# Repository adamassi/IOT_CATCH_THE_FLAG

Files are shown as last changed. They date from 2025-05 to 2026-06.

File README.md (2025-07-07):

## CAPTURE THE FLAG Project by :  Firas Hilu, Adam Assi, Jimmy Bittar
  Type It, Robot Builds It!
  The project is a robot that receives a word from the user, detects relevant letter cubes, and places them in the correct order in a designated area.
## Details about the project
   Main Features:
  - Real-time 3D object tracking via OptiTrack
  - Autonomous path planning using RRT* for obstacle avoidance
  - Full spelling pipeline: input, detection, pickup, transport, and placement
  This project demonstrates a flexible robotic framework for real-time
  object handling using motion capture and path planning.

## Hardware used:
  - ESP32 CH9102
  - Car platform PCB
  - L293D driver
  - 4 DC motors
  - Active Buzzer
  - Micro servo
  - 9V / 12V battery
  - LM2596 DC-DC Buck Converter Module
  - Optitrack markers
  * note: in the platform we used, the ENA and ENB of the driver were connected together, so in order to be able to control the speed of each side separately, we didnt use libraries for controlling the speed, but we wrote the code of the ESP for controlling the motors using PWM on th IN1, IN2, IN3, IN4.
    
## Folder description :
* ESP32: source code for the esp
* path_algorithms: files used in planning the algorithm
* Documentation: wiring diagram + poster + 3d printed parts
* Unit Tests: tests for individual hardware components
* PARAMETERS.py: contains the parameters and settings that can be modified in the code - hardcoded parameters.

## ESP32 SDK version used in this project: 
"esp32" SDK version 2.0.17 by Espressif Systems.

## Arduino/ESP32 libraries used in this project:
* WiFi - version 2.0.17 (from esp32 core by Espressif Systems)
* AsyncTCP - version 3.3.2
* ESPAsyncWebServer - version 3.6.0
* ESP32Servo - version 3.0.6

## Connection diagram:
diagram

## Project Poster:
Capture_The_Falg_poster

This project is part of ICST - The Interdisciplinary Center for Smart Technologies, Taub Faculty of Computer Science, Technion
https://icst.cs.technion.ac.il/

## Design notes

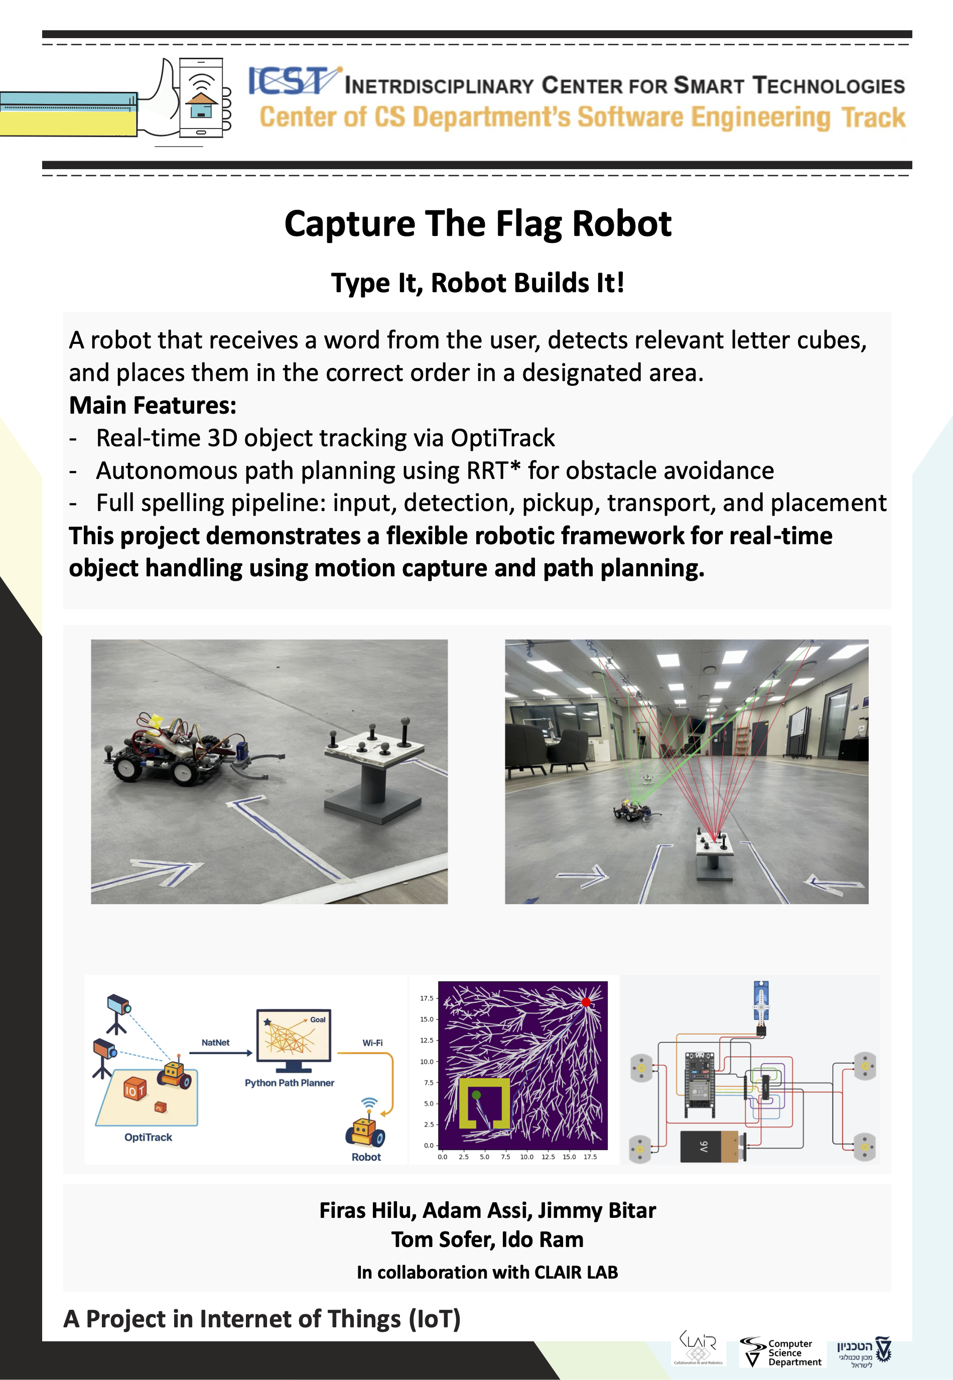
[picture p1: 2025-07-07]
assests/Capture_The_Falg_poster.png

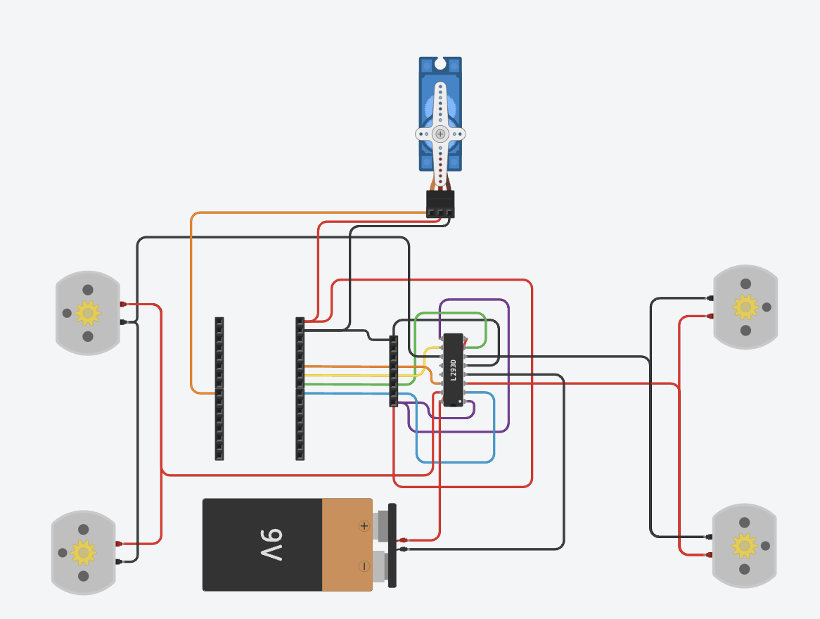
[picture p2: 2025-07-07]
assests/diagram.png

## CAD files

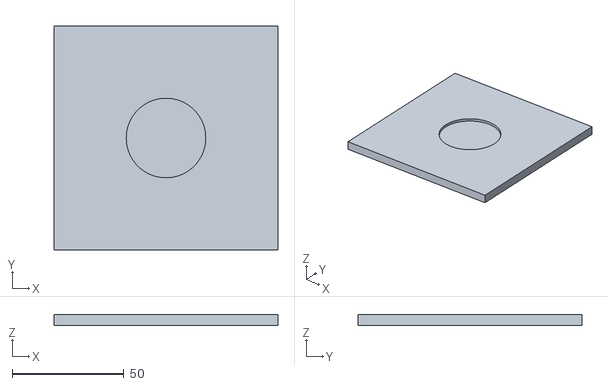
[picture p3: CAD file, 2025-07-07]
assests/3d_printing/top_part.stl
100.0 x 100.0 x 5.00

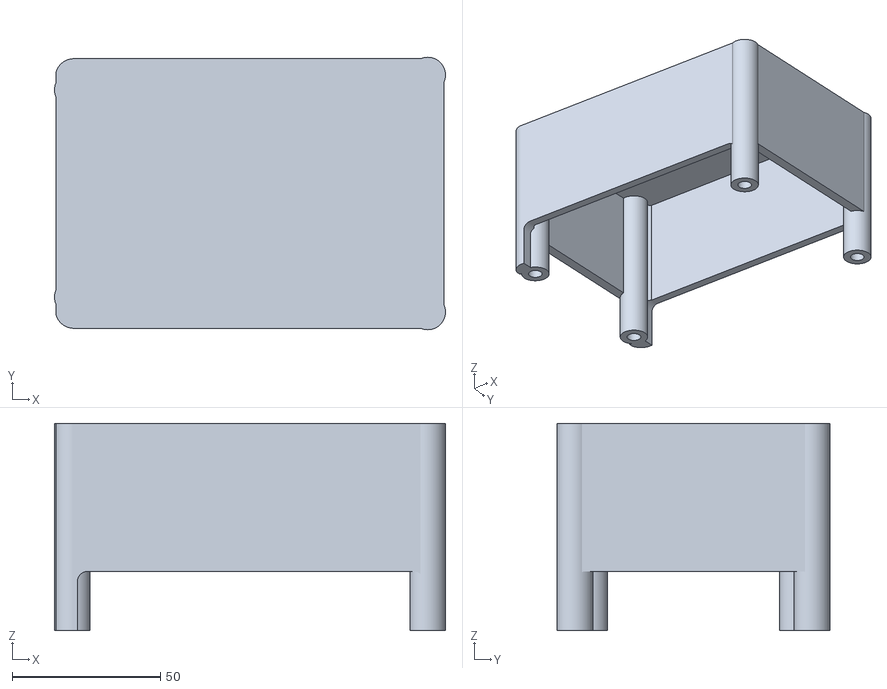
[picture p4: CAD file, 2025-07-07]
assests/3d_printing/IOT_robot_case.stl
132.0 x 92.0 x 70.0

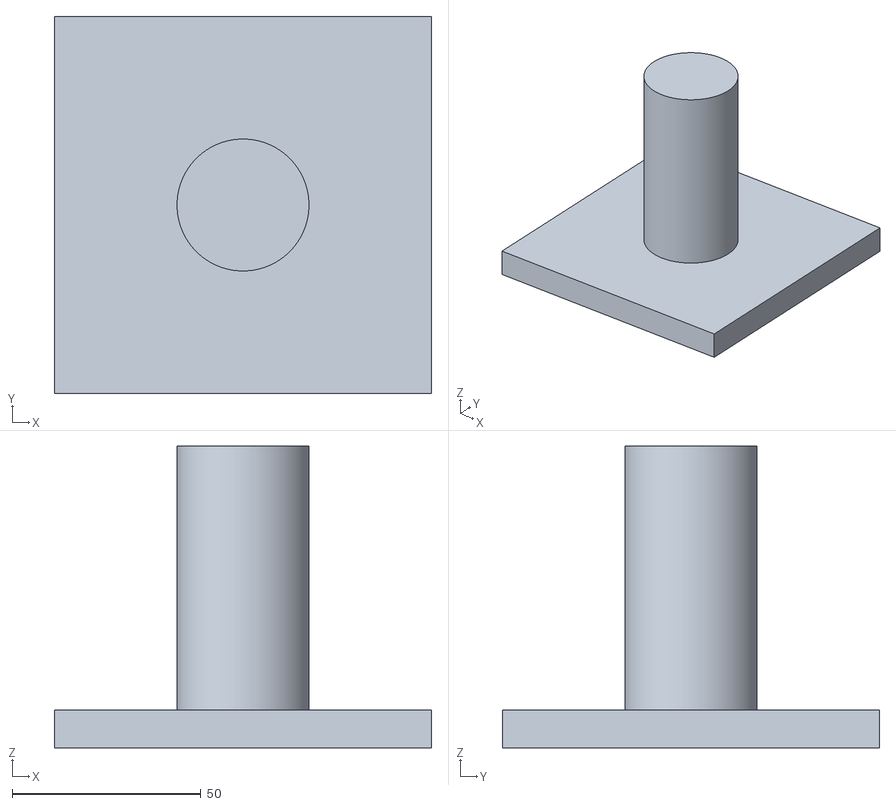
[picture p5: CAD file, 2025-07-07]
assests/3d_printing/base_part.stl
100.0 x 100.0 x 80.0

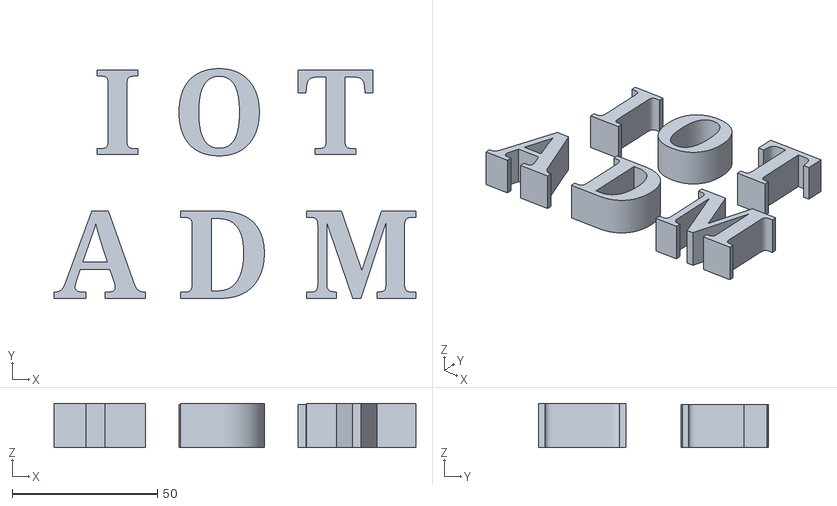
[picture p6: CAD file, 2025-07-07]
assests/3d_printing/letters.stl
124.5 x 79.0 x 15.1

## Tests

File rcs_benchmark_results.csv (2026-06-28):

run_index | start_x | start_y | goal_x | goal_y | success | path_length | time_seconds
1 | -0.2099 | -0.9652 | 1.0777 | -0.6967 | 1 | 1.8018 | 4.375302
2 | 0.3596 | -0.9543 | -1.3736 | 0.0534 | 1 | 2.4399 | 14.167814
3 | -1.69 | -0.6077 | 1.5716 | -1.6594 | 1 | 4.2871 | 45.078915
4 | 2.8974 | 0.3119 | 2.6241 | -0.6205 | 1 | 1.1972 | 1.89203
5 | -0.5476 | 1.877 | 3.1428 | -1.5742 | 1 | 5.5842 | 58.885434
6 | 2.1586 | 0.9652 | 3.498 | -1.1967 | 1 | 3.18 | 24.669612
7 | -2.0207 | 1.7797 | -3.8503 | -0.3494 | 1 | 3.1694 | 22.683516
8 | -3.6902 | -0.1207 | 0.8395 | -0.6447 | 1 | 6.4344 | 38.249741
9 | 0.0886 | -0.6658 | -2.5479 | -0.3662 | 1 | 4.2241 | 38.933603
10 | -0.2804 | 1.0991 | 1.4629 | -1.0494 | 1 | 2.9599 | 27.331372
11 | -1.9977 | -1.2285 | 3.2131 | -0.4567 | 1 | 7.0341 | 65.185963
12 | 0.279 | -0.5471 | -2.6854 | -0.0939 | 1 | 4.1928 | 24.214959
13 | -2.4742 | 0.8403 | 1.1673 | 0.029 | 1 | 4.7138 | 26.431936
14 | 0.036 | -1.6032 | 0.8234 | 0.67 | 1 | 3.2667 | 5.709921
15 | -3.3224 | -1.4972 | -0.6924 | 0.8983 | 1 | 3.9911 | 6.893601
16 | -3.33 | 0.2276 | -2.1221 | 1.3979 | 1 | 1.8093 | 0.941159
17 | 2.8716 | -0.8355 | 3.4137 | -0.3585 | 1 | 0.7308 | 0.493155
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

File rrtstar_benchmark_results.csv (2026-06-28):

run_index | start_x | start_y | goal_x | goal_y | success | path_length | time_seconds
1 | 2.8825 | -1.5846 | 0.3958 | -1.8374 | 1 | 2.5739 | 0.457899
2 | 2.4377 | 0.7294 | -2.9072 | -1.2642 | 1 | 5.913 | 0.504726
3 | -3.7297 | -0.6265 | -3.007 | 0.1249 | 1 | 1.2856 | 0.219742
4 | -0.7057 | -0.5253 | -0.6808 | 0.3606 | 1 | 0.9703 | 0.186255
5 | -0.6485 | -1.8988 | 0.8873 | -1.7884 | 1 | 1.6308 | 0.198096
6 | 0.0811 | -1.3204 | 2.2872 | -1.0073 | 1 | 2.3257 | 0.280202
7 | 1.957 | -1.6852 | -0.2862 | -1.6783 | 1 | 2.5583 | 0.299143
8 | -3.2804 | 1.6072 | -2.7467 | -0.3219 | 1 | 2.4723 | 0.321626
9 | -2.6899 | 0.793 | 3.1886 | 1.4603 | 1 | 6.3777 | 0.76219
10 | 0.7464 | -0.3033 | -2.0113 | -0.315 | 1 | 2.9263 | 0.278232
11 | 0.7957 | 1.8009 | -2.0193 | -0.1743 | 1 | 3.6606 | 0.349373
12 | -1.2972 | 1.2988 | -3.6014 | -0.1318 | 1 | 2.7683 | 0.281091
13 | -3.0521 | 1.72 | 1.8487 | 1.638 | 1 | 5.0096 | 0.3935
14 | 0.0059 | -1.6769 | -0.4604 | 0.3023 | 1 | 2.1244 | 0.232812
15 | -0.361 | 1.0712 | 1.503 | 0.5845 | 1 | 2.0824 | 0.275678
16 | -3.6821 | 0.1028 | 3.3516 | -1.6248 | 1 | 7.5785 | 0.660558
17 | 0.1883 | 1.8255 | 1.5458 | -1.3127 | 1 | 3.4499 | 0.43348
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

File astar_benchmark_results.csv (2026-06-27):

run_index | start_x | start_y | goal_x | goal_y | success | path_length | time_seconds
1 | 3.6898 | 0.2818 | 1.3687 | -0.8646 | 1 | 2.5888 | 0.567852
2 | 0.469 | -1.6728 | 1.8175 | -1.5676 | 1 | 1.3526 | 0.446736
3 | 3.3861 | 0.8448 | 3.6451 | 0.0311 | 1 | 0.8539 | 0.512764
4 | 0.1999 | -1.7176 | -0.1534 | 0.0411 | 1 | 1.7938 | 0.467693
5 | 1.7088 | 1.1359 | -0.5832 | -0.4615 | 1 | 2.7938 | 0.718417
6 | 1.9346 | -0.1076 | 2.7815 | -1.0605 | 1 | 1.2749 | 0.466033
7 | 0.329 | -1.2217 | -2.6064 | -1.4685 | 1 | 2.9458 | 0.424948
8 | -0.262 | 1.2786 | 1.3341 | 1.1252 | 1 | 1.6034 | 0.453101
9 | -1.4095 | -0.8809 | 2.7189 | 1.1898 | 1 | 4.6185 | 0.564341
10 | 0.1079 | -0.4643 | 0.1198 | 0.8552 | 1 | 1.3196 | 0.4681
11 | 2.794 | 0.4617 | 1.2769 | -0.6978 | 1 | 1.9094 | 0.512458
12 | -3.0079 | 1.3215 | -2.1455 | -0.5634 | 1 | 2.0728 | 0.491075
13 | -1.4265 | -1.2238 | -0.615 | -0.7387 | 1 | 0.9455 | 0.600992
14 | -0.4027 | -0.1542 | -0.8228 | 0.1311 | 1 | 0.5079 | 0.477805
15 | -2.8718 | -0.2451 | -3.5092 | -0.6103 | 1 | 0.7346 | 0.464533
16 | 1.8232 | -0.5731 | -0.3897 | 0.8329 | 1 | 2.6217 | 0.441428
17 | 0.5724 | -0.9694 | 2.3217 | 1.7248 | 1 | 3.4668 | 0.462753
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

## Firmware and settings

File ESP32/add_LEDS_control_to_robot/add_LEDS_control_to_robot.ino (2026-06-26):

#include <WiFi.h>
#include <AsyncTCP.h>
#include <ESPAsyncWebServer.h>
#include <ESP32Servo.h>
#include <Adafruit_NeoPixel.h>


#ifdef __AVR__
 #include <avr/power.h> // Required for 16 MHz Adafruit Trinket
#endif










// Which pin on the Arduino is connected to the NeoPixels?
#define LEDPIN  19
// How many NeoPixels are attached to the Arduino?
#define NUMPIXELS 6 // Popular NeoPixel ring size

Adafruit_NeoPixel pixels(NUMPIXELS, LEDPIN, NEO_GRB + NEO_KHZ800);


Servo myServo;


// WiFi credentials  router name and password
const char *ssid = "IOT_project";     //remember to change
const char *password = "Arduino123";  //remember to change

int ENA_pin = 13;

int IN1 = 27;
int IN2 = 26;
int IN3 = 25;
int IN4 = 33;

const int servoPin = 15;
//beeper
const int beeperPin = 23;
TaskHandle_t beepingTaskHandle = NULL;
volatile bool keepBeeping = false;

String slider_value = "0";
int pwm_power_value = 45;

int servoAngle = 10;

const int frequency = 500;
// l1() l4 responsible go backward
// l2 (right) and l3(left) responsible go forward 
const int pwm_channel1 = 5;
const int pwm_channel2 = 2;
const int pwm_channel3 = 3;
const int pwm_channel4 = 4;
// const int servo_channel = 1;
const int resolution = 8;

const char *input_parameter = "value";

AsyncWebServer server(80);

const char index_html[] PROGMEM = R"rawliteral(
<!DOCTYPE HTML><html>
<head>
  <meta name="viewport" content="width=device-width, initial-scale=1">
  <title>DC Motor Speed Control Web Server</title>
  <style>
    html {font-family: Times New Roman; display: inline-block; text-align: center;}
    h2 {font-size: 2.3rem;}
    p {font-size: 2.0rem;}
    body {max-width: 400px; margin:0px auto; padding-bottom: 25px;}
    .slider { -webkit-appearance: none; margin: 14px; width: 360px; height: 25px; background: #4000ff;
      outline: none; -webkit-transition: .2s; transition: opacity .2s;}
    .slider::-webkit-slider-thumb {-webkit-appearance: none; appearance: none; width: 35px; height: 35px; background:#01070a; cursor: pointer;}
    .slider::-moz-range-thumb { width: 35px; height: 35px; background: #01070a; cursor: pointer; } 
    .btn {padding: 16px 24px; margin: 10px; font-size: 18px; background-color: #008CBA; color: white; border: none; cursor: pointer; border-radius: 8px;}
    .btn:hover {background-color: #005f73;}
  </style>
</head>
<body>
  <p><strong>Servo Angle</strong></p>
  <span id="servo_angle_display">%SERVOANGLE%</span>°
  <input type="range" onchange="updateServoAngle(this)" id="servoSlider" min="0" max="90" value="%SERVOANGLE%" step="1" class="slider">


  <h2>DC Motor Speed Control Web Server</h2>
  <p><span id="textslider_value">%SLIDERVALUE%</span></p>
  <p><input type="range" onchange="updateSliderPWM(this)" id="pwmSlider" min="-255" max="255" value="%SLIDERVALUE%" step="1" class="slider"></p>
  
  <p><strong>PWM Power</strong></p>
  <p><span id="pwm_power_display">%SLIDERPWMVALUE%</span></p>
  <input type="range" onchange="updatePWMSlider(this)" id="pwmPowerSlider" min="0" max="255" value="%SLIDERPWMVALUE%" step="1" class="slider">
  

  <p>
    <button class="btn" onclick="goForward()">Forward</button><br>
    <button class="btn" onclick="turnLeft()">Left</button>
    <button class="btn" onclick="stopMotor()">Stop</button>
    <button class="btn" onclick="turnRight()">Right</button><br>
    <button class="btn" onclick="goBackward()">Backward</button>
  </p>

<script>

function updateServoAngle(element) {
  var angle = document.getElementById("servoSlider").value;
  document.getElementById("servo_angle_display").innerHTML = angle;
  var xhr = new XMLHttpRequest();
  xhr.open("GET", "/servo?value=" + angle, true);
  xhr.send();
}

function updateSliderPWM(element) {
  var slider_value = document.getElementById("pwmSlider").value;
  document.getElementById("textslider_value").innerHTML = slider_value;
  var xhr = new XMLHttpRequest();
  xhr.open("GET", "/slider?value=" + slider_value, true);
  xhr.send();
}

function updatePWMSlider(element) {
  var pwm_value = document.getElementById("pwmPowerSlider").value;
  document.getElementById("pwm_power_display").innerHTML = pwm_value;
  var xhr = new XMLHttpRequest();
  xhr.open("GET", "/set_pwm_power?value=" + pwm_value, true);
  xhr.send();
}

function stopMotor() {
  var xhr = new XMLHttpRequest();
  xhr.open("GET", "/stop", true);
  xhr.send();
  document.getElementById("pwmSlider").value = 0;
  document.getElementById("textslider_value").innerHTML = 0;
}

function goForward() {
  var xhr = new XMLHttpRequest();
  xhr.open("GET", "/go", true);
  xhr.send();
}

function goBackward() {
  var xhr = new XMLHttpRequest();
  xhr.open("GET", "/back", true);
  xhr.send();
}

function turnLeft() {
  var xhr = new XMLHttpRequest();
  xhr.open("GET", "/left", true);
  xhr.send();
}

function turnRight() {
  var xhr = new XMLHttpRequest();
  xhr.open("GET", "/right", true);
  xhr.send();
}

window.addEventListener("keydown", function(e) {
  if(["ArrowUp", "ArrowDown", "ArrowLeft", "ArrowRight", " "].includes(e.key)) {
    e.preventDefault();
  }
}, false);

document.addEventListener("keydown", function(event) {
 switch(event.key) {
    case "ArrowUp":
      goForward();
      break;
    case "ArrowDown":
      goBackward();
      break;
    case "ArrowLeft":
      turnLeft();
      break;
    case "ArrowRight":
      turnRight();
      break;
    case " ":
      stopMotor();
      break;
  }
});
</script>
</body>
</html>
)rawliteral";


// String processor(const String &var) {
//   if (var == "SLIDERVALUE") {
//     return slider_value;
//   }
//   return String();
// }

// String processor(const String &var) {
//   if (var == "SLIDERVALUE") {
//     return slider_value;
//   } else if (var == "SLIDERPWMVALUE") {
//     return String(pwm_power_value);
//   }
//   return String();
// }

String processor(const String &var) {
  if (var == "SLIDERVALUE") {
    return slider_value;
  } else if (var == "SLIDERPWMVALUE") {
    return String(pwm_power_value);
  } else if (var == "SERVOANGLE") {
    return String(servoAngle);
  }
  return String();
}


//beeper
void repeatedBeepTask(void *param) {
  int *durations = (int *)param;
  int onDuration = durations[0];
  int offDuration = durations[1];
  delete[] durations;

  while (keepBeeping) {
    digitalWrite(beeperPin, HIGH);
    vTaskDelay(onDuration / portTICK_PERIOD_MS);
    digitalWrite(beeperPin, LOW);
    vTaskDelay(offDuration / portTICK_PERIOD_MS);
  }

  digitalWrite(beeperPin, LOW);  // Ensure off
  beepingTaskHandle = NULL;
  vTaskDelete(NULL);
}



void setup() {
  Serial.begin(115200);
  delay(1000);
  pinMode(ENA_pin, OUTPUT);
  pinMode(IN1, OUTPUT);
  pinMode(IN2, OUTPUT);
  pinMode(IN3, OUTPUT);
  pinMode(IN4, OUTPUT);
  pinMode(LEDPIN, OUTPUT);

  ledcSetup(pwm_channel1, frequency, resolution);
  ledcSetup(pwm_channel2, frequency, resolution);
  ledcSetup(pwm_channel3, frequency, resolution);
  ledcSetup(pwm_channel4, frequency, resolution);

  ledcAttachPin(IN1, pwm_channel1);
  ledcAttachPin(IN2, pwm_channel2);
  ledcAttachPin(IN3, pwm_channel3);
  ledcAttachPin(IN4, pwm_channel4);

  digitalWrite(ENA_pin, LOW);
  ledcWrite(pwm_channel1, 0);
  ledcWrite(pwm_channel2, 0);
  ledcWrite(pwm_channel3, 0);
  ledcWrite(pwm_channel4, 0);
  digitalWrite(ENA_pin, HIGH);


  pixels.begin();
  pixels.clear(); // Initialize all pixels to 'off'


  for(int i=0; i<NUMPIXELS; i++){
      pixels.setPixelColor(i, pixels.Color(255, 0, 0)); // Red color
  }
  pixels.show(); // Update the strip to display the new colors


  // ledcSetup(servo_channel, frequency, resolution);
  // ledcAttachPin(servoPin, servo_channel);
  myServo.attach(servoPin);

  pinMode(beeperPin, OUTPUT);
  digitalWrite(beeperPin, LOW);  // Ensure it's off initially


  WiFi.begin(ssid, password);
  while (WiFi.status() != WL_CONNECTED) {
    // delay(1000);
    // Serial.println("Connecting...");
    pixels.clear(); // Clear previous colors
    delay(500);
    
    for(int i=0; i<NUMPIXELS; i++){
      pixels.setPixelColor(i, pixels.Color(0, 0, 255)); // blue color
    }
  Serial.println("Connecting...");
  pixels.show(); // Update the strip to display the new colors
  delay(500);
  }
  for(int i=0; i<NUMPIXELS; i++){
    pixels.setPixelColor(i, pixels.Color(0, 255, 0)); // green color
  }
  pixels.show(); // Update the strip to display the new colors

  Serial.println(WiFi.localIP());

  server.on("/", HTTP_GET, [](AsyncWebServerRequest *request) {
    request->send_P(200, "text/html", index_html, processor);
  });



  server.on("/slider", HTTP_GET, [](AsyncWebServerRequest *request) {
    String message;
    if (request->hasParam(input_parameter)) {
      message = request->getParam(input_parameter)->value();
      slider_value = message;

      int val = slider_value.toInt();
      int pwm_value = abs(val);  // Always a positive PWM

      // Determine motor direction
      if (val > 0) {
        // Forward
        ledcWrite(pwm_channel1, 0);    // IN1 LOW
        ledcWrite(pwm_channel2, val);  // IN2 PWM -> Forward speed
        ledcWrite(pwm_channel3, val);  // IN3 PWM -> Forward speed
        ledcWrite(pwm_channel4, 0);    // IN4 LOW

      } else if (val < 0) {
        // Reverse
        val = -val;                    // Make val positive for PWM
        ledcWrite(pwm_channel1, val);  // IN1 PWM -> Reverse speed
        ledcWrite(pwm_channel2, 0);    // IN2 LOW
        ledcWrite(pwm_channel3, 0);    // IN3 LOW
        ledcWrite(pwm_channel4, val);  // IN4 PWM -> Reverse speed

      } else {
        // Stop
        ledcWrite(pwm_channel1, 0);
        ledcWrite(pwm_channel2, 0);
        ledcWrite(pwm_channel3, 0);
        ledcWrite(pwm_channel4, 0);
      }

      // Apply PWM regardless of direction
    } else {
      message = "No message sent";
    }
    Serial.println(message);
    request->send(200, "text/plain", "OK");
  });

  server.on("/set_pwm_power", HTTP_GET, [](AsyncWebServerRequest *request) {
    if (request->hasParam(input_parameter)) {
      pwm_power_value = request->getParam(input_parameter)->value().toInt();
      Serial.print("PWM power updated: ");
      Serial.println(pwm_power_value);
    }
    request->send(200, "text/plain", "PWM power updated");
  });

  server.on("/stop", HTTP_GET, [](AsyncWebServerRequest *request) {
    //slider_value = "0";
    ledcWrite(pwm_channel1, 0);
    ledcWrite(pwm_channel2, 0);
    ledcWrite(pwm_channel3, 0);
    ledcWrite(pwm_channel4, 0);

    request->send(200, "text/plain", "Motor stopped");
  });

  server.on("/go", HTTP_GET, [](AsyncWebServerRequest *request) {
    //slider_value = "150";
    ledcWrite(pwm_channel1, 0);
    ledcWrite(pwm_channel2, 250);
    ledcWrite(pwm_channel3, 250);
    ledcWrite(pwm_channel4, 0);

    request->send(200, "text/plain", "Motor go");
  });

  server.on("/back", HTTP_GET, [](AsyncWebServerRequest *request) {
    //slider_value = "150";
    ledcWrite(pwm_channel1, 250);
    ledcWrite(pwm_channel2, 0);
    ledcWrite(pwm_channel3, 0);
    ledcWrite(pwm_channel4, 250);

    request->send(200, "text/plain", "Back");
  });

  server.on("/right", HTTP_GET, [](AsyncWebServerRequest *request) {
    //slider_value = "150";
    int speed = pwm_power_value;
    if (request->hasParam(input_parameter)) {
      speed = request->getParam(input_parameter)->value().toInt();
    }
    ledcWrite(pwm_channel1, speed);
    ledcWrite(pwm_channel2, 0);
    ledcWrite(pwm_channel3, speed);
    ledcWrite(pwm_channel4, 0);

    request->send(200, "text/plain", "turn right");
  });
  server.on("/right_moving", HTTP_GET, [](AsyncWebServerRequest *request) {
    //slider_value = "150";
    int speed = pwm_power_value;
    if (request->hasParam(input_parameter)) {
      speed = request->getParam(input_parameter)->value().toInt();
    }
    ledcWrite(pwm_channel1, speed);
    ledcWrite(pwm_channel2, 0);
    ledcWrite(pwm_channel3, speed);
    ledcWrite(pwm_channel4, 0);

    request->send(200, "text/plain", "turn right");
  });

  server.on("/left", HTTP_GET, [](AsyncWebServerRequest *request) {
    //slider_value = "150";
    int speed = pwm_power_value;
    if (request->hasParam(input_parameter)) {
      speed = request->getParam(input_parameter)->value().toInt();
    }
    ledcWrite(pwm_channel1, 0);
    ledcWrite(pwm_channel2, speed);
    ledcWrite(pwm_channel3, 0);
    ledcWrite(pwm_channel4, speed);

    request->send(200, "text/plain", "turn left");
  });

  server.on("/steer", HTTP_GET, [](AsyncWebServerRequest *request) {
    int left_speed = 0;
    int right_speed = 0;

    // Check if both parameters exist
    if (request->hasParam("left") && request->hasParam("right")) {
      left_speed = request->getParam("left")->value().toInt();
      right_speed = request->getParam("right")->value().toInt();
    } else {
      request->send(400, "text/plain", "Missing 'left' or 'right' parameter");
      return;
    }

    // Set motor speeds
    ledcWrite(pwm_channel1, 0);
    ledcWrite(pwm_channel2, right_speed);
    ledcWrite(pwm_channel3, left_speed);
    ledcWrite(pwm_channel4, 0);

    // Respond to client
    request->send(200, "text/plain", "Steering updated");
  });

  server.on("/servo", HTTP_GET, [](AsyncWebServerRequest *request) {
    if (request->hasParam(input_parameter)) {
      int angle = request->getParam(input_parameter)->value().toInt();
      angle = constrain(angle, 0, 90);  // Ensure within valid range
      myServo.write(angle);
      servoAngle = angle;
      Serial.printf("Servo angle set to: %d\n", angle);
      request->send(200, "text/plain", "Servo angle set to " + String(angle));
    } else {
      request->send(400, "text/plain", "Missing angle parameter");
    }
  });

  server.on("/beep", HTTP_GET, [](AsyncWebServerRequest *request) {
    if (request->hasParam("duration")) {
      int duration = request->getParam("duration")->value().toInt();
      duration = constrain(duration, 1, 5000);  // Max 5 seconds safety limit

      digitalWrite(beeperPin, HIGH);  // Turn beeper on
      Serial.printf("Beeping for %d ms\n", duration);

      // Use a timer (non-blocking) via a task or schedule
      // For now, use delay in a simple task
      xTaskCreatePinnedToCore(
        [](void *param) {
          int d = *((int *)param);
          vTaskDelay(d / portTICK_PERIOD_MS);
          digitalWrite(beeperPin, LOW);  // Turn it off
          delete (int *)param;
          vTaskDelete(NULL);
        },
        "BeeperTask", 2048, new int(duration), 1, NULL, 1);

      request->send(200, "text/plain", "Beeping for " + String(duration) + " ms");
    } else {
      request->send(400, "text/plain", "Missing 'duration' parameter");
    }
  });

  server.on("/start_beeping", HTTP_GET, [](AsyncWebServerRequest *request) {
    if (beepingTaskHandle != NULL) {
      request->send(400, "text/plain", "Beeping already running");
      return;
    }

    if (request->hasParam("on") && request->hasParam("off")) {
      int onTime = request->getParam("on")->value().toInt();
      int offTime = request->getParam("off")->value().toInt();

      onTime = constrain(onTime, 10, 5000);
      offTime = constrain(offTime, 10, 5000);

      keepBeeping = true;

      int *durations = new int[2]{ onTime, offTime };

      xTaskCreatePinnedToCore(
        repeatedBeepTask, "RepeatedBeepTask", 2048, durations, 1, &beepingTaskHandle, 1);

      request->send(200, "text/plain", "Started beeping");
    } else {
      request->send(400, "text/plain", "Missing 'on' or 'off' parameter");
    }
  });

  server.on("/stop_beeping", HTTP_GET, [](AsyncWebServerRequest *request) {
    keepBeeping = false;
    request->send(200, "text/plain", "Stopped beeping");
  });
  server.on("/connecting",HTTP_GET, [](AsyncWebServerRequest *request) {
    
    pixels.clear(); // Set all pixel colors to 'off'

    for (int i = 0; i < NUMPIXELS; i++) {
        pixels.setPixelColor(i, pixels.Color(0, 0, 255)); // Blue
      }
    
      pixels.show();
    request->send(200, "text/plain", "LED blue");
  });
  server.on("/lights_peach", HTTP_GET, [](AsyncWebServerRequest *request) {
  pixels.clear();

  for (int i = 0; i < NUMPIXELS; i++) {
    pixels.setPixelColor(i, pixels.Color(0, 50, 250)); // Peach
  }

  pixels.show();
  request->send(200, "text/plain", "Lights set to peach");
});


server.on("/lights_color", HTTP_GET, [](AsyncWebServerRequest *request) {
  if (
    request->hasParam("red") &&
    request->hasParam("green") &&
    request->hasParam("blue")
  ) {
    int red = request->getParam("red")->value().toInt();
    int green = request->getParam("green")->value().toInt();
    int blue = request->getParam("blue")->value().toInt();

    red = constrain(red, 0, 255);
    green = constrain(green, 0, 255);
    blue = constrain(blue, 0, 255);

    pixels.clear();

    for (int i = 0; i < NUMPIXELS; i++) {
      pixels.setPixelColor(i, pixels.Color(red, green, blue));
    }

    pixels.show();

    request->send(200, "text/plain", "Lights color updated");
  } else {
    request->send(400, "text/plain", "Missing red, green, or blue parameter");
  }
});

server.begin();





  server.begin();
}

void loop() {

  // No need for code here
}

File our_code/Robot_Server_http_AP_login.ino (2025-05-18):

#include <WiFiManager.h>
#include "L298NX2.h"
#include <WiFi.h>
#include <ESP32Servo.h>
#include <ESPmDNS.h>
#include <WebServer.h>
#include <Preferences.h>

hw_timer_t * timerDCMotor = NULL;
// hw_timer_t * timerServo = NULL;
//Servo myServo;
//const unsigned int servoPin = 18;
//const unsigned int servoPWMChannel = 0; // Use PWM channel 0 for servo



/*********************
//  IN1 + IN2 Right Side
//  IN3 + IN4 Left  Side
//  IN2 + IN3 HIGH => Forward
//  5V for enable / controll speed for both sides together
**********************/

#define EN_SHARED 14
#define PWM_CHANNEL 0

// Motors Pin definition
const unsigned int IN1 = 27;
const unsigned int IN2 = 26;
//const unsigned int EN_A = 14;
//const unsigned int motorPWMChannelA = 1; // Use PWM channel 1 for motor A

const unsigned int IN3 = 25;
const unsigned int IN4 = 33;
//const unsigned int EN_B = 12;
//const unsigned int motorPWMChannelB = 2; // Use PWM channel 2 for motor B

// Initialize both motors
L298NX2 motors(EN_SHARED, IN2, IN1, EN_SHARED, IN3, IN4);

WiFiManager wifiManager;
WebServer server(80);
Preferences preferences;

bool ledState = LOW; // Maintain the LED state

    volatile char M1_Direction = 'F';
    
    volatile char M2_Direction = 'F';

    volatile int speed_1 = 0;
    volatile int speed_2 = 0;
    volatile int angle = 90;

void IRAM_ATTR onDCTimer() {
  // Control DC motor speed
    motors.setSpeedA(speed_1);
    motors.setSpeedB(speed_2);
    
    if (M1_Direction == 'F') {
        motors.forwardA();
    } else {
        motors.backwardA();
    }

    if (M2_Direction == 'F') {
        motors.forwardB();
    } else {
        motors.backwardB();
    }
}

void IRAM_ATTR onServoTimer() {
  // Control Servo position
  myServo.write(angle);
}


void handleMotionCommand(String uri) {
    if (uri.length() != 14) return; // Validate length

    M1_Direction = uri.charAt(1);
    String M1_Speed = uri.substring(2, 5);
    M2_Direction = uri.charAt(5);
    String M2_Speed = uri.substring(6, 9);
    String angle_wrap = uri.substring(9, 10) + uri.substring(13, 14);
    String angle_str = uri.substring(10, 13);

    if (angle_wrap != "AA") return; // Validate angle wrap

    if ((M1_Direction != 'F' && M1_Direction != 'B') || (M2_Direction != 'F' && M2_Direction != 'B')) return; // Validate directions

    speed_1 = M1_Speed.toInt();
    speed_2 = M2_Speed.toInt();
    
    //bool ServoExecuted = false;
    if (angle >= 60 && angle <= 120) {
        Serial.print("angle set to: ");
        Serial.println(angle);
        angle = angle_str.toInt();
    } else {
        return; // Invalid angle
    }

    Serial.print("speed_1 set to: ");
    Serial.println(speed_1);
    Serial.print(", isForward_1: ");
    Serial.println(M1_Direction == 'F');
    Serial.print("speed_2 set to: ");
    Serial.println(speed_2);
    Serial.print(", isForward_2: ");
    Serial.println(M2_Direction == 'F');



}

void setup() {
    Serial.begin(115200);
    myServo.attach(servoPin);
    pinMode(2, OUTPUT);
    pinMode(4, OUTPUT);
    digitalWrite(2, HIGH);
    pinMode(15, OUTPUT);
    

    motors.setSpeed(70);


    // Initialize timer for DC motor
    timerDCMotor = timerBegin(0, 80, true); // Timer 0, prescaler 80, count up
    timerAttachInterrupt(timerDCMotor, &onDCTimer, true); // Attach ISR to timer
    timerAlarmWrite(timerDCMotor, 5000, true); // Set alarm to 5ms (5000us) for faster updates
    timerAlarmEnable(timerDCMotor); // Enable timer alarm

    // Initialize timer for Servo
    timerServo = timerBegin(1, 80, true); // Timer 1, prescaler 80, count up
    timerAttachInterrupt(timerServo, &onServoTimer, true); // Attach ISR to timer
    timerAlarmWrite(timerServo, 20000, true); // Set alarm (20000us for 50Hz servo control)
    timerAlarmEnable(timerServo); // Enable timer alarm

    // Try to connect to saved WiFi credentials, if it fails, start AP
    if (!wifiManager.autoConnect("ESP32_AP", "12345678")) {
        Serial.println("Failed to connect to WiFi. Resetting...");
        delay(3000);
        ESP.restart();
    }
    digitalWrite(2, LOW);
    Serial.println("WiFi connected.");
    Serial.println("IP address: ");
    Serial.println(WiFi.localIP());

    // Start the mDNS responder for esp32.local
    if (!MDNS.begin("esp32")) { // Domain name esp32.local
        Serial.println("Error setting up MDNS responder!");
    }
    Serial.println("mDNS responder started");

    server.on("/", HTTP_GET, []() {
        server.send(200, "text/html",
                    "<h1>Welcome to ESP32</h1>"
                    "<p><a href=\"/H2\">Turn LED2 (red) on</a></p>"
                    "<p><a href=\"/H4\">Turn LED4 (blue) on</a></p>"
                    "<p><a href=\"/H15\">Turn LED15 (green) on</a></p>"
                    "<p><a href=\"/L2\">Turn LED2 off</a></p>"
                    "<p><a href=\"/L4\">Turn LED4 off</a></p>"
                    "<p><a href=\"/L15\">Turn LED15 off</a></p>"
                    
                    
                    "<p> deg 60 </p>"
                    "<p><a href=\"/F254F254A060A\">Drive forward fast</a></p>"
                    "<p><a href=\"/F150F150A060A\">Drive forward slow</a></p>"
                    "<p><a href=\"/B254B254A060A\">Drive backward fast</a></p>"
                    "<p><a href=\"/B150B150A060A\">Drive backward slow</a></p>"
                    "<p><a href=\"/F000F000A060A\">Stop</a></p>"

                    "<p> deg 90 </p>"
                    "<p><a href=\"/F254F254A090A\">Drive forward fast</a></p>"
                    "<p><a href=\"/F150F150A090A\">Drive forward slow</a></p>"
                    "<p><a href=\"/B254B254A090A\">Drive backward fast</a></p>"
                    "<p><a href=\"/B150B150A090A\">Drive backward slow</a></p>"
                    "<p><a href=\"/F000F000A090A\">Stop</a></p>"

                    "<p> deg 120 </p>"
                    "<p><a href=\"/F254F254A120A\">Drive forward fast</a></p>"
                    "<p><a href=\"/F150F150A120A\">Drive forward slow</a></p>"
                    "<p><a href=\"/B254B254A120A\">Drive backward fast</a></p>"
                    "<p><a href=\"/B150B150A120A\">Drive backward slow</a></p>"
                    "<p><a href=\"/F000F000A120A\">Stop</a></p>"

                    "<p>IP Address: " + WiFi.localIP().toString() + "</p>"
                    "<p><a href=\"/reset\">Reset WiFi Settings</a></p>"
                    "<h2>Control Robot</h2>"
                    "<form action=\"/send_command\" method=\"GET\">"
                    "Speed 1: <input type=\"text\" name=\"speed1\" maxlength=\"3\"><br>"
                    "Speed 2: <input type=\"text\" name=\"speed2\" maxlength=\"3\"><br>"
                    "Angle: <input type=\"text\" name=\"angle\" maxlength=\"3\"><br>"
                    "<input type=\"submit\" value=\"Send\">"
                    "</form>");
    });
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

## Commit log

2025-05-18 7arak al esp32
2025-05-27 add open to the servo at the end of the code
2025-06-12 Implement RRT* make the robot steer smoothly
2025-06-12 Add steering functions
2025-07-03 Add live plotting functionality and data handling for chaser and target positions
    - Implemented a new script for live plotting of chaser and target positions using Matplotlib.
    - Integrated data reception from the OptiTrack system to track chaser and target movements.
    - Added functions to handle turning and moving towards the target based on real-time data.
    - Enhanced plotting functions to visualize the paths of the chaser and target with appropriate axis labels and limits.
    - Included error handling for connection issues with the OptiTrack system.
    [steering_robot.ino]
2025-07-03 Refactor chaser data handling to simplify frame processing and update target handling for multiple cubes
2025-07-06 fixed print posesions from optitrack
2025-07-07 add servo request in go_to_goal function for path correction
2025-07-07 def check_esp_http(ip=ESPConfig.ESP_IP): try: response = requests.get(f"http://{ip}", timeout=2) if response.status_code == 200: print("ESP is online and responding.") return True else: raise Connect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
2025-07-08 deleted a lot of prints
2026-02-23 Implement core game structure with menu and game screens
    - Added main application logic in app.py to initialize Pygame and manage screen transitions.
    - Created config.py for centralized configuration settings including window dimensions, colors, and font loading.
    - Developed a base screen class in base.py to define common screen methods.
    - Implemented GameScreen in game.py to handle game logic, buttons, and display output.
    - Created MenuScreen in menu.py for the main menu interface with navigation buttons.
    - Introduced ScreenManager in screen_manager.py to manage screen transitions and state.
    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
2026-05-21 Refactor condition in go_to_goal function to use current_target_id for clarity
2026-05-24 Add initial LEDs_control.ino file for NeoPixel control
2026-05-26 Add initial implementation of LED control and web server for DC motor and servo management
2026-05-26 Update NeoPixel pin definition and enhance setup for LED initialization; add pixel color setting in loop
2026-06-05 Add LED control and web server implementation for steering robot; include NeoPixel setup and motor control features
2026-06-05 Enhance Cube and Location classes with validation and position retrieval methods; update planner to handle dynamic obstacles and improve board limit checks.
2026-06-05 Add move_cube_blocking_base function to sample random positions and calculate paths
2026-06-05 Add LED control functionality and new web server endpoints for robot commands
2026-06-05 Add LED control functionality and web server integration for robot commands
2026-06-05 Enhance WiFi connection feedback by adding LED color indication during connection attempts
2026-06-05 Add green LED indication during setup to enhance visual feedback
2026-06-05 Improve WiFi connection feedback by adding LED color indication during connection attempts
2026-06-26 Add peach light control and request handling for robot LEDs
    - Implemented a new endpoint to set the robot's RGB LEDs to peach.
    - Added a function to send a request for the peach light setting.
    - Created a test script to verify the peach light functionality.
2026-06-26 Rename "Extra" button to "Word Bank" in ConfigureScreen and remove unused word bank button from RobotConfigScreen; add robot beeping stop request in ProcessRunner and create robot_muted.flag file.
2026-06-26 Add Word Bank configuration screen and integrate cube management; update LED control and input handling
2026-06-26 Add dynamic LED color control and update color constants; modify test script for new functionality
2026-06-26 Add celebration_colors function and integrate light color indication in main flow
2026-06-27 Add benchmark results for RRT* algorithm in CSV format
    [astar_benchmark_results.csv, rrtstar_benchmark_results.csv]
2026-06-27 Add timer functionality to GameScreen and improve process runner command execution
2026-06-27 Add RCS Planner and integrate into path planning
    - Implemented RCSPlanner class for path planning using a coarse-to-fine approach.
    - Updated get_path_to_goal function to support RCS planner alongside existing planners (RRT* and A*).
    - Enhanced error handling for invalid start/goal positions.
    - Added tests for A*, RCS, and RRT* planners to validate functionality.
    - Updated benchmark results with new planning data.
    [rrtstar_benchmark_results.csv]
2026-06-28 Add RCS benchmarking script and results CSV file
    [rcs_benchmark_results.csv]
2026-06-28 Refactor game screens and process management
    - Updated GameScreen to use main.py instead of thread_control_test.py.
    - Enhanced ManualControlScreen to use safe_call for command requests.
    - Added wrapped text drawing functionality in RobotConfigScreen for better UI.
    - Integrated NotificationManager into ScreenManager for error handling.
    - Improved ProcessRunner with error notifications and safe command execution.
    - Updated robotCommands to include timeout for requests and raise exceptions on failure.
    - Added NotificationManager for displaying messages and errors in the UI.
    - Created a flag file to manage robot muted state.
2026-07-03 Refactor and remove obsolete files and functions
    - Deleted old main scripts: 4_main_with_Astar.py and 4_main_with_bezier.py
    - Removed unused test scripts: test_peach_requst.py and thread_control_test.py
    - Cleaned up create_obstacles.py by removing redundant JSON appending
    - Updated planner.py to improve visualization timing and logic
    - Added main guard to pure_pursuit_first_try.py for better script execution
    - Removed robot_muted.flag as it is no longer needed
